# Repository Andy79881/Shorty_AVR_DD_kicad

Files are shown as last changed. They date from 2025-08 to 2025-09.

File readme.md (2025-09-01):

# Shorty_AVR_DD - Kicad based design files

## What is it for?

Shorty is short circuit finder, usable for checking PCB, for example. Where normal digital multimeters do not have enough of resolution to differentiate low PCB resistance in order of tens of miliohms to allow exact short circuit location, shorty comes to help.

## Content of this repository

This repository consists of the Kicad files. The design is done with Kicad 9.x.

Code Baseline:
---
- Refer to Readme of [Shorty_AVR_DD](https://github.com/Andy79881/Shorty_AVR_DD).

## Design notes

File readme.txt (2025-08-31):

Export Gerber and Drill files
-------------------------------

Aisler: https://community.aisler.net/t/support-for-traditional-gerber-files/99

1.) Dateinamen des Export können so bleiben!

Lesson Learned
---------------

Aisler HASL Design-Regeln verletzt -> ENIG musste genutzt werden (teurer aber auch höherwertiger)
-> min via annular ring 200um -> aktuell Design rules 300um Bohrung und 600um Via = 150um annular ring
-> für HASL müsste DK Durchmesser 700um bei 300um Bohrdurchmesser betragen

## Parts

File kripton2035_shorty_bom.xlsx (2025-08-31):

Reference | Value | Datasheet | Footprint | Qty | DNP
C1,C2,C3,C4,C5,C6,C7,C8,C9 | 100n | ~ | Capacitor_SMD:C_0805_2012Metric_Pad1.18x1.45mm_HandSolder | 9
C12,L1 | 4.7u | https://www.fastrongroup.com/uploads/datasheets/Series/Complete-DataSheet/1212FPS.pdf,~ | Capacitor_SMD:C_1210_3225Metric_Pad1.33x2.70mm_HandSolder,user_global_passive_lib:L_Fastron-1212FPS | 2
C13 | 10u | ~ | Capacitor_SMD:C_1210_3225Metric_Pad1.33x2.70mm_HandSolder | 1
D1 | 1N4148W | https://www.vishay.com/docs/85748/1n4148w.pdf | Diode_SMD:D_SOD-123 | 1
D2 | BZV55B5V1 | https://assets.nexperia.com/documents/data-sheet/BZV55_SER.pdf | Diode_SMD:D_MiniMELF | 1
F1 | FSMD0500805R | ~ | Fuse:Fuse_0805_2012Metric_Pad1.15x1.40mm_HandSolder | 1
FB1 | FerriteBead | ~ | Inductor_SMD:L_0805_2012Metric_Pad1.15x1.40mm_HandSolder | 1
J1,J5 | Conn_01x04_Pin | ~ | Connector_JST:JST_XH_S4B-XH-A_1x04_P2.50mm_Horizontal,Connector_PinHeader_2.54mm:PinHeader_1x04_P2.54mm_Vertical | 2
J2 | Conn_01x03_Pin | ~ | Connector_PinHeader_2.54mm:PinHeader_1x03_P2.54mm_Vertical | 1 | DNP
J3,J6 | Conn_01x03_Pin | ~ | Connector_JST:JST_PH_B3B-PH-K_1x03_P2.00mm_Vertical,Connector_PinHeader_2.54mm:PinHeader_1x03_P2.54mm_Vertical | 2
J4 | Conn_01x02_Pin | ~ | Connector_JST:JST_PH_B2B-PH-K_1x02_P2.00mm_Vertical | 1
Q1 | IRLML2244 | https://www.infineon.com/dgdl/irlml6401pbf.pdf?fileId=5546d462533600a401535668b96d2634 | Package_TO_SOT_SMD:SOT-23 | 1
Q2 | BC817 | https://www.onsemi.com/pub/Collateral/BC818-D.pdf | Package_TO_SOT_SMD:SOT-23 | 1
R1,R17 | 100 | ~ | Resistor_SMD:R_0805_2012Metric_Pad1.20x1.40mm_HandSolder,Resistor_SMD:R_MELF_MMB-0207 | 2
R2,R3,R4 | 1 | ~ | Resistor_SMD:R_MiniMELF_MMA-0204 | 3
R5,R14 | 10k | ~ | Resistor_SMD:R_0805_2012Metric_Pad1.20x1.40mm_HandSolder | 2
R6,R11,R12 | 10k | ~ | Resistor_SMD:R_0805_2012Metric_Pad1.20x1.40mm_HandSolder,Resistor_SMD:R_1206_3216Metric_Pad1.30x1.75mm_HandSolder | 3 | DNP
R7 | 22k | ~ | Resistor_SMD:R_0805_2012Metric_Pad1.20x1.40mm_HandSolder | 1
R8,R15,R19 | 1k | ~ | Resistor_SMD:R_0805_2012Metric_Pad1.20x1.40mm_HandSolder | 3
R9 | 0 | ~ | Resistor_SMD:R_0805_2012Metric_Pad1.20x1.40mm_HandSolder | 1
R10 | 330 | ~ | Resistor_SMD:R_0805_2012Metric_Pad1.20x1.40mm_HandSolder | 1
R13 | 1Meg | ~ | Resistor_SMD:R_0805_2012Metric_Pad1.20x1.40mm_HandSolder | 1
R16 | 100k | ~ | Resistor_SMD:R_0805_2012Metric_Pad1.20x1.40mm_HandSolder | 1
R18 | 470 | ~ | Resistor_SMD:R_0805_2012Metric_Pad1.20x1.40mm_HandSolder | 1
R20,R23 | 27k | ~ | Resistor_SMD:R_0805_2012Metric_Pad1.20x1.40mm_HandSolder | 2
R21 | 309k | ~ | Resistor_SMD:R_0603_1608Metric_Pad0.98x0.95mm_HandSolder | 1
R22 | 180k | ~ | Resistor_SMD:R_0603_1608Metric_Pad0.98x0.95mm_HandSolder | 1
SW1 | SW_Push | ~ | user_global_con_lib:SW_SPST_Omron_B3F-40xx | 1
U1 | MCP3421A0T-ECH | http://ww1.microchip.com/downloads/en/DeviceDoc/22003e.pdf | Package_TO_SOT_SMD:SOT-23-6 | 1
U2 | AVR32DD20x-xSO | https://www.microchip.com/en-us/product/AVR32DD20 | Package_SO:SOIC-20W_7.5x12.8mm_P1.27mm | 1
U3 | AD8551AR | https://www.analog.com/media/en/technical-documentation/data-sheets/AD8551_8552_8554.pdf | Package_SO:SOIC-8_3.9x4.9mm_P1.27mm | 1
U4 | Display_OLED_SSD1306_I2C_0.91 | ~ | Custom_Displays:SSD1306-0.91-OLED-4pin-128x32 | 1
U7 | MCP1640Bx-xCHY | http://ww1.microchip.com/downloads/en/DeviceDoc/20002234D.pdf | Package_TO_SOT_SMD:SOT-23-6 | 1

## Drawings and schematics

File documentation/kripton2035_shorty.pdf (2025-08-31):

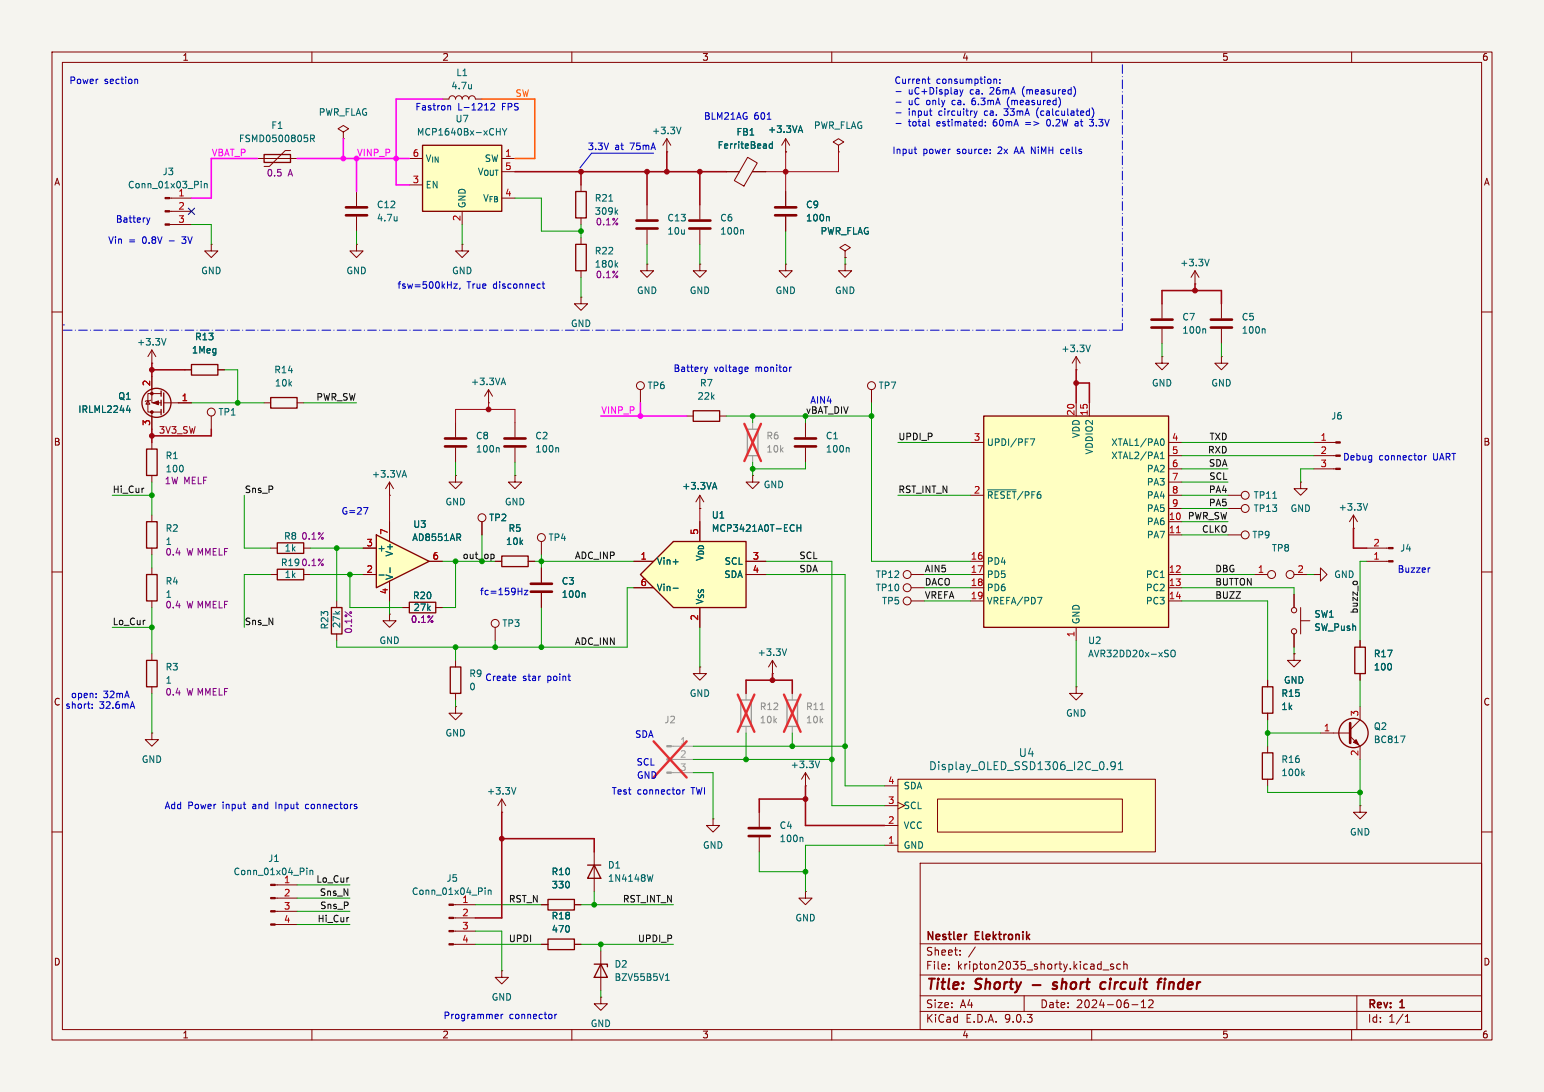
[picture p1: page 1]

3.3V at 75mA Create star point

- uC only ca. 6.3mA (measured)

2 SW 1 V_{OUT} 5 V_{FB}4 U7 MCP1640Bx-xCHY GND

Input power source: 2x AA NiMH cells

Add Power input and Input connectors

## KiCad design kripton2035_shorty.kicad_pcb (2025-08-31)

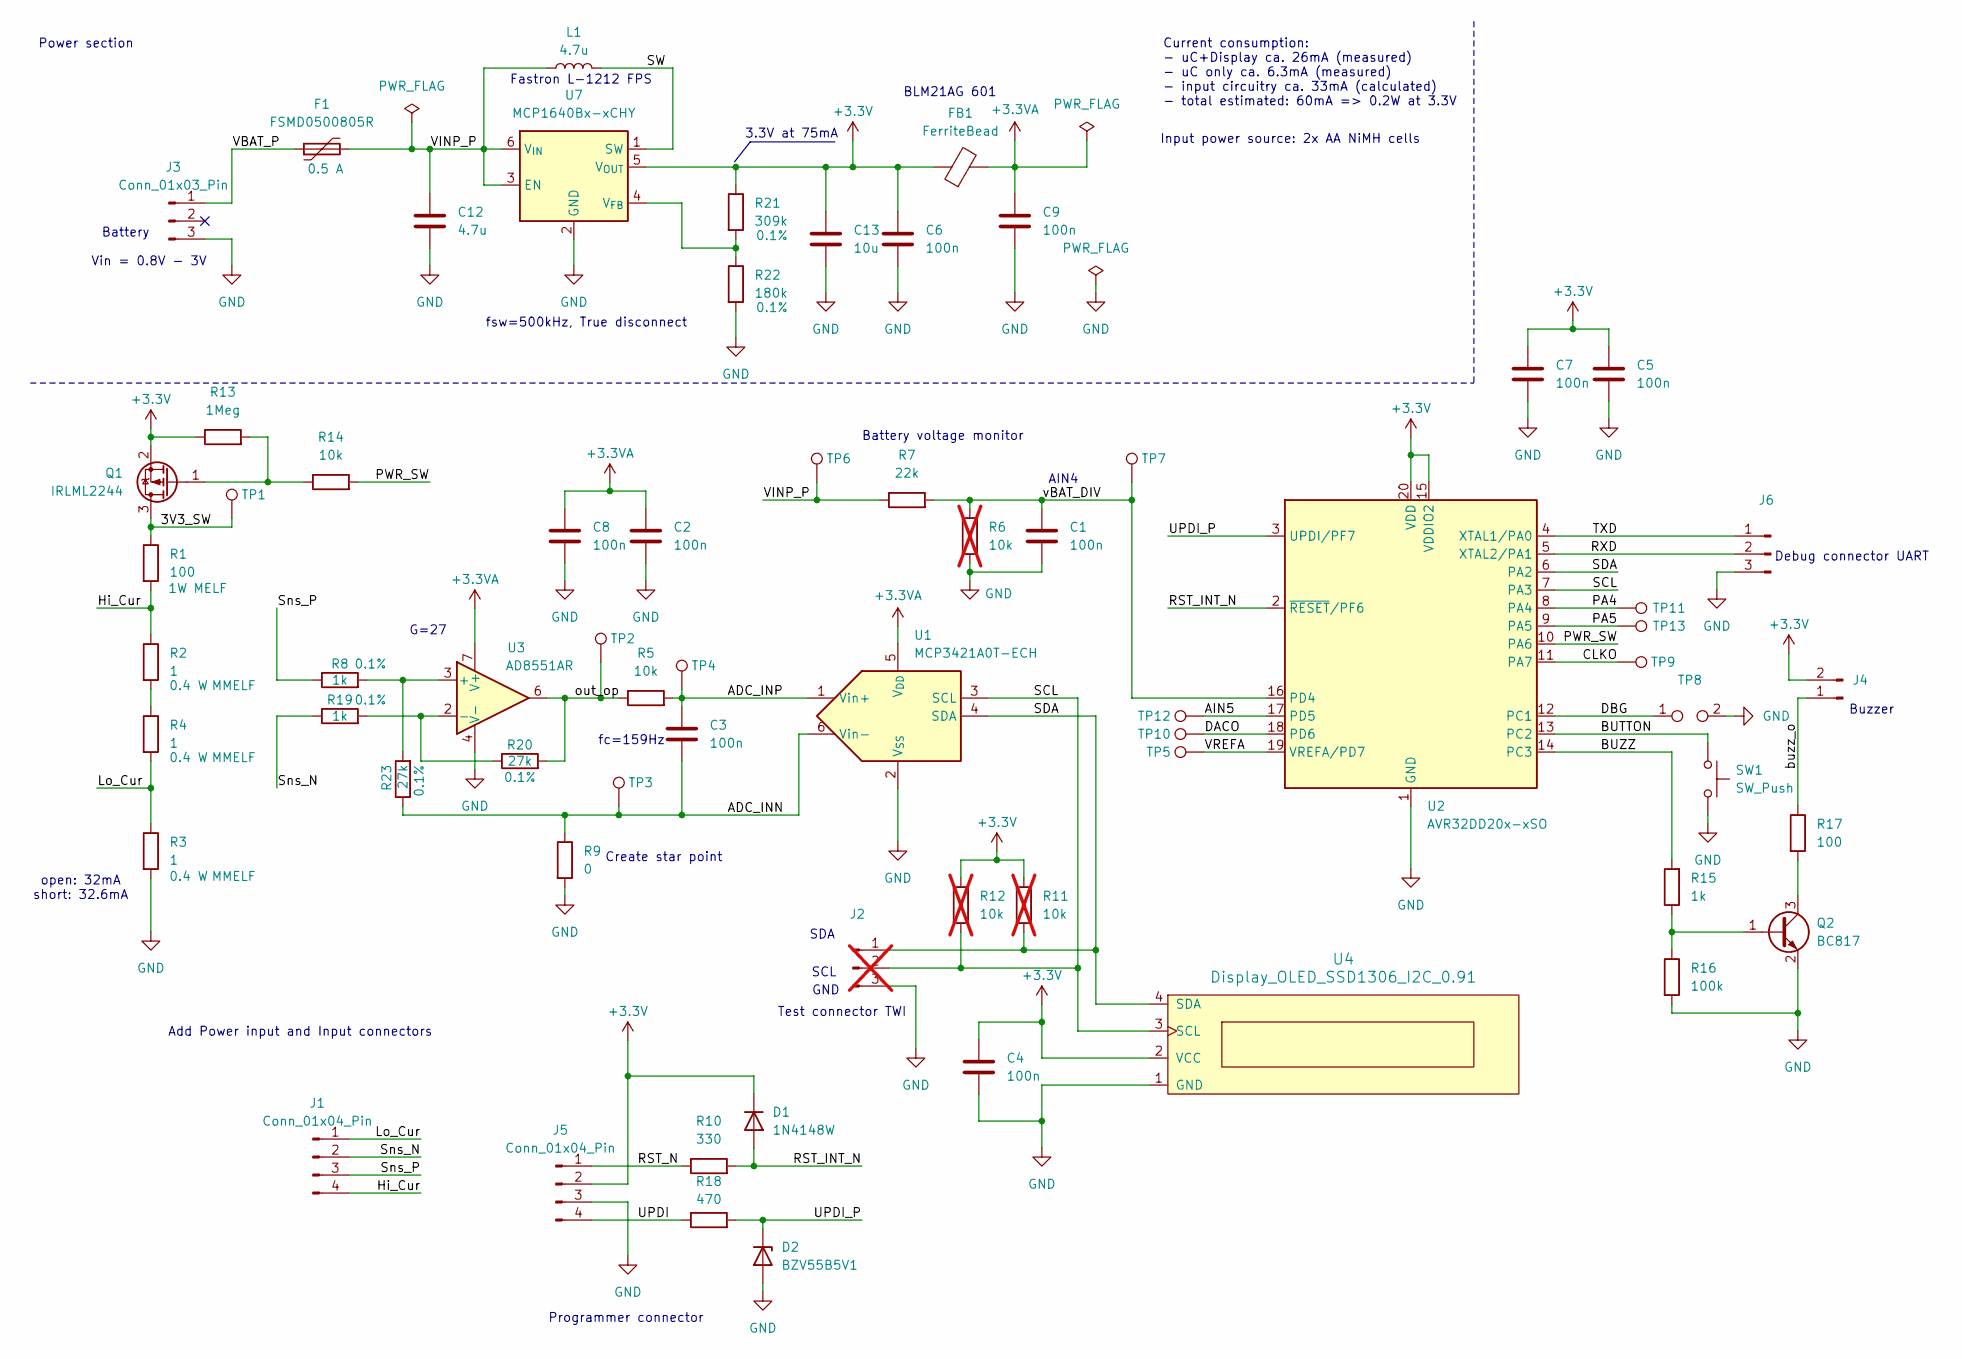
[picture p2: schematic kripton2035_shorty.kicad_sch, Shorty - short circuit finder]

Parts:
C1, C2, C3, C4, C5, C6, C7, C8, C9: 100n; C_0805_2012Metric_Pad1.18x1.45mm_HandSolder
C12: 4.7u; C_0805_2012Metric_Pad1.18x1.45mm_HandSolder
C13: 10u; C_0805_2012Metric_Pad1.18x1.45mm_HandSolder
D1: 1N4148W; D_SOD-123
D2: BZV55B5V1; D_MiniMELF
F1: FSMD0500805R; Fuse_0805_2012Metric_Pad1.15x1.40mm_HandSolder; Voltage 6 V
FB1: FerriteBead; L_0805_2012Metric_Pad1.15x1.40mm_HandSolder
J1: Conn_01x04_Pin; JST_XH_S4B-XH-A_1x04_P2.50mm_Horizontal
J2: Conn_01x03_Pin; PinHeader_1x03_P2.54mm_Vertical; not fitted
J3: Conn_01x03_Pin; JST_PH_B3B-PH-K_1x03_P2.00mm_Vertical
J4: Conn_01x02_Pin; JST_PH_B2B-PH-K_1x02_P2.00mm_Vertical
J5: Conn_01x04_Pin; PinHeader_1x04_P2.54mm_Vertical
J6: Conn_01x03_Pin; PinHeader_1x03_P2.54mm_Vertical
L1: 4.7u; L_Fastron-1212FPS
Q1: IRLML2244; SOT-23
Q2: BC817; SOT-23
R1: 100; R_MELF_MMB-0207
R2, R3, R4: 1; R_MiniMELF_MMA-0204
R5, R14: 10k; R_0805_2012Metric_Pad1.20x1.40mm_HandSolder
R6: 10k; R_0805_2012Metric_Pad1.20x1.40mm_HandSolder; not fitted
R7: 22k; R_0805_2012Metric_Pad1.20x1.40mm_HandSolder
R8, R15, R19: 1k; R_0805_2012Metric_Pad1.20x1.40mm_HandSolder
R9: 0; R_0805_2012Metric_Pad1.20x1.40mm_HandSolder
R10: 330; R_0805_2012Metric_Pad1.20x1.40mm_HandSolder
R11, R12: 10k; R_1206_3216Metric_Pad1.30x1.75mm_HandSolder; not fitted
R13: 1Meg; R_0805_2012Metric_Pad1.20x1.40mm_HandSolder
R16: 100k; R_0805_2012Metric_Pad1.20x1.40mm_HandSolder
R17: 100; R_0805_2012Metric_Pad1.20x1.40mm_HandSolder
R18: 470; R_0805_2012Metric_Pad1.20x1.40mm_HandSolder
R20, R23: 27k; R_0805_2012Metric_Pad1.20x1.40mm_HandSolder
R21: 309k; R_0603_1608Metric_Pad0.98x0.95mm_HandSolder
R22: 180k; R_0603_1608Metric_Pad0.98x0.95mm_HandSolder
SW1: SW_Push; SW_SPST_Omron_B3F-40xx
TP1, TP2, TP3, TP4, TP5, TP6, TP7, TP9, TP10, TP11, TP12, TP13: TestPoint; TestPoint_Pad_D1.0mm
TP8: TestPoint_2Pole; TestPoint_2Pads_Pitch2.54mm_Drill0.8mm
U1: MCP3421A0T-ECH; SOT-23-6
U2: AVR32DD20x-xSO; SOIC-20W_7.5x12.8mm_P1.27mm
U3: AD8551AR; SOIC-8_3.9x4.9mm_P1.27mm
U4: Display_OLED_SSD1306_I2C_0.91; SSD1306-0.91-OLED-4pin-128x32
U7: MCP1640Bx-xCHY; SOT-23-6

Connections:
+3.3V: C4.1, C5.1, C6.1, C7.1, C13.1, D1.1 (K), FB1.1, J4.2, J5.2, Q1.2 (S), R11.2, R12.2, R13.1, R21.1, U2.15 (VDDIO2), U2.20 (VDD), U4.2 (VCC), U7.5 (V_{OUT})
+3.3VA: C2.1, C8.1, C9.1, FB1.2, U1.5 (V_{DD}), U3.7 (V+)
/3V3_SW: Q1.3 (D), R1.1, TP1.1
/ADC_INN: C3.2, R9.1, R23.1, TP3.1, U1.6 (Vin-)
/ADC_INP: C3.1, R5.2, TP4.1, U1.1 (Vin+)
/AIN5: TP12.1, U2.17 (PD5)
/BUTTON: SW1.1, U2.13 (PC2)
/BUZZ: R15.2, U2.14 (PC3)
/CLKO: TP9.1, U2.11 (PA7)
/DACO: TP10.1, U2.18 (PD6)
/DBG: TP8.1, U2.12 (PC1)
/Hi_Cur: J1.4, R1.2, R2.1
/Lo_Cur: J1.1, R3.1, R4.2
/PA4: TP11.1, U2.8 (PA4)
/PA5: TP13.1, U2.9 (PA5)
/PWR_SW: R14.2, U2.10 (PA6)
/RST_INT_N: D1.2 (A), R10.2, U2.2 (~RESET/PF6)
/RST_N: J5.1, R10.1
/RXD: J6.2, U2.5 (XTAL2/PA1)
/SCL: J2.2, R12.1, U1.3 (SCL), U2.7 (PA3), U4.3 (SCL)
/SDA: J2.1, R11.1, U1.4 (SDA), U2.6 (PA2), U4.4 (SDA)
/SW: L1.2, U7.1 (SW)
/Sns_N: J1.2, R19.1
/Sns_P: J1.3, R8.1
/TXD: J6.1, U2.4 (XTAL1/PA0)
/UPDI: J5.4, R18.1
/UPDI_P: D2.1 (K), R18.2, U2.3 (UPDI/PF7)
/VBAT_P: F1.1, J3.1
/VINP_P: C12.1, F1.2, L1.1, R7.1, TP6.1, U7.3 (EN), U7.6 (V_{IN})
/VREFA: TP5.1, U2.19 (VREFA/PD7)
/buzz_o: J4.1, R17.1
/out_op: R5.1, R20.2, TP2.1, U3.6
/vBAT_DIV: C1.1, R6.1, R7.2, TP7.1, U2.16 (PD4)
GND: C1.2, C2.2, C4.2, C5.2, C6.2, C7.2, C8.2, C9.2, C12.2, C13.2, D2.2 (A), J2.3, J3.3, J5.3, J6.3, Q2.2 (E), R3.2, R6.2, R9.2, R16.2, R22.2, SW1.2, TP8.2, U1.2 (V_{SS}), U2.1 (GND), U3.4 (V-), U4.1 (GND), U7.2 (GND)
unnamed: Q1.1 (G), R13.2, R14.1
unnamed: Q2.1 (B), R15.1, R16.1
unnamed: Q2.3 (C), R17.2
unnamed: R2.2, R4.1
unnamed: R8.2, R23.2, U3.3 (+)
unnamed: R19.2, R20.1, U3.2 (-)
unnamed: R21.2, R22.1, U7.4 (V_{FB})

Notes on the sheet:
Test connector TWI
Buzzer
Current consumption: - uC+Display ca. 26mA (measured) - uC only ca. 6.3mA (measured) - input circuitry ca. 33mA (calculated) - total estimated: 60mA => 0.2W at 3.3V
fc=159Hz
Vin = 0.8V - 3V
Add Power input and Input connectors
3.3V at 75mA
Fastron L-1212 FPS
AIN4
Power section
open: 32mA short: 32.6mA
SCL
Battery voltage monitor
Battery
Input power source: 2x AA NiMH cells
G=27
Debug connector UART
GND
SDA
Create star point
Programmer connector
fsw=500kHz, True disconnect
BLM21AG 601

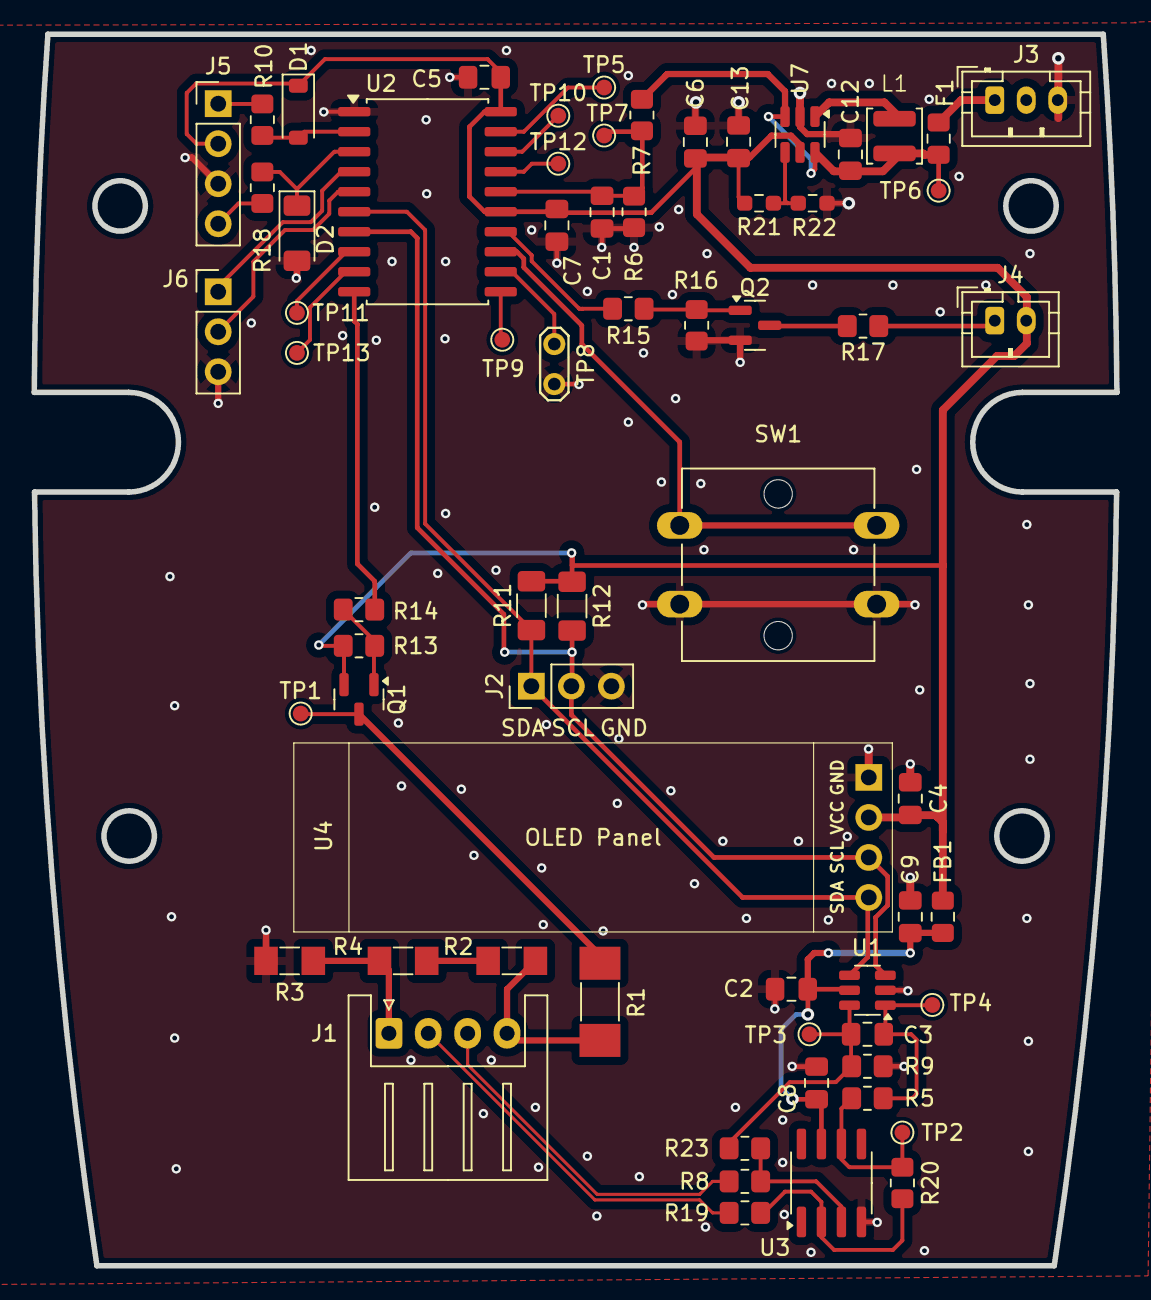
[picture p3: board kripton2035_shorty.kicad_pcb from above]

Board: 2 copper layers, 68.7 x 78.2 mm, 66 parts (0 on the bottom side), 41 nets.
